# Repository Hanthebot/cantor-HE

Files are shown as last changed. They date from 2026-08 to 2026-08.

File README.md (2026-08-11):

# cantor-HE
42 key column staggered split, now with hall effect (WIP)

> Warning! The hardware should work fine, but firmware was not verified yet due to flashing issue.

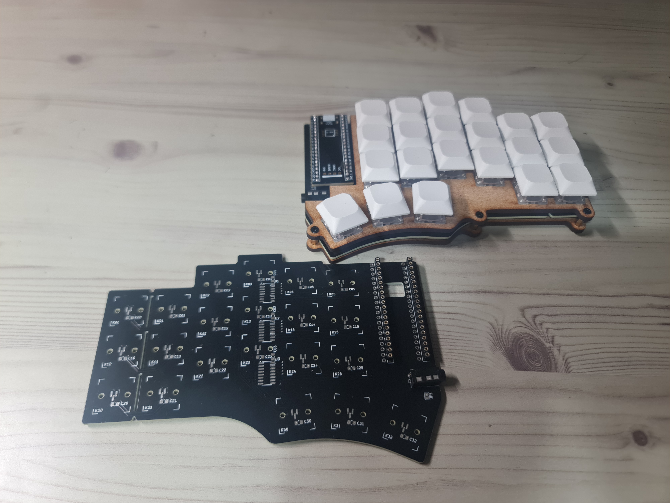
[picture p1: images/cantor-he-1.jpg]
cantor-he


Hall-effect variant of [Cantor](https://github.com/diepala/cantor), a 42-key split keyboard.

Wooting compatible, reversible, qmk/vial support, and sharing PCB dimension with official Cantor

Firmware / schematics based on [TrueStrike42](https://github.com/byungyoonc/TrueStrike42)

## Preparation

### Board
| Component | Qty |
| --- | --- |
| PCB | 2 |
| SOT-23 SS49E | 42  |
| SOIC-16 74HC4051(D)  | 6 |
| 0805 0.1uf capacitor | 48  |
| PJ320A TRRS socket | 2 |
| Blackpill MCU | 2 |
- For capacitor, 0.1~1uf should be fine
- And obviously, USB-C cable of your choice (with machine) and TRS/TRRS cable of your choice

### Case
- Option A: 3D printed case (I bet you can find one for Cantor)
- Option B: Cheap plate cut
  - requires heat insert and standoff
  - 3T mdf panel of A4 size can fit 2x top & bottom plate
      - and costs about $1
  - plate file provided in this repo
- I do not think original barebone design will work well, as switches are not soldered / mechanically connected.

| Component | Qty |
| --- | --- |
| M2 screw 6mm | 12  |
| M2 heat insert 3*3 | 12  |
| M2 standoff 7mm + 3mm head | 12  |
- Flathead screw was used
- Standoff can be shorter or longer - but I recommend 5mm at least

### Switches
| Component | Qty |
| --- | --- |
| Wooting compatible magnetic switch | 42  |
- While those without side pins should be fine, I'd use one with side pins so that they fix better
- Firmware fix may be required to use the opposite polarity

## [Build guide](GUIDE.md)
WIP. You may check images folder / [Boardloaf-HE's build guide](https://github.com/Hanthebot/Boardloaf-HE/blob/main/GUIDE.md). 

\+ jump back for side detection, firmware is shared between halves

Almost the only difference is that you can solder SOIC-16 multiplexor on either side, preferably at the back of the keyboard.

## Features
- Supports both APC and rapid trigger
- Cheap, simple, and working
- 3 multiplexor on each side, scanning 7 keys per mux

## Changes from Boardloaf-HE
- full duplex communication
- reversible SOIC-16 footprint
- except that, firmware remains largely identical.
- STM32F4x1 MCU, so key precision is expected to have been improved by ~= 10x

## Remarks
- Initial config recommendation: 30% / 20% / 20% / 10% / 10% / 20% (APC act / release; RT init dead / act offset / release offset / bottom dead)
- More documentation: to be done
- Case
  - if your case works for official Cantor, it must work for this
- Random
  - PCB schematics are almost directly from TrueStrike42

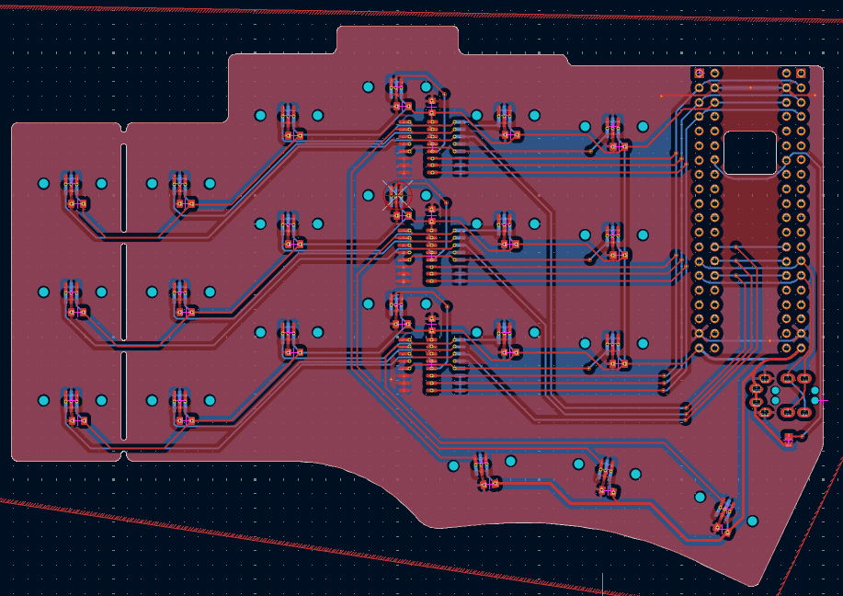
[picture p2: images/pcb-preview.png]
PCB


## Sponsorship
PCB was generously sponsored by [PCBWay](https://www.pcbway.com/)! Their PCB was indeed of high quality. I did not go with options like matte coating or ENIG, but the board was generally better.

Apart from their great quality, what I felt different was their customer service. There were real human involved in production / communication process and you could feel that they want to help you. In the world filled by chatbot / hallucination, such experience is very rare indeed.

If you are designing a PCB & want some human to check it beforehand, I think PCBWay is superb. They will save you trial and errors.

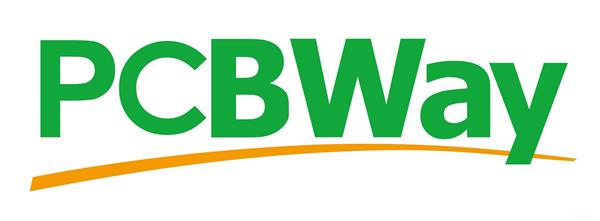
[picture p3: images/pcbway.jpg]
PCBWay


## Licenses
All code under firmware folder, along with HW, follows GPL v3.
- inherited from TrueStrike42 / Cantor respectively.
- reversible SOT23 / SOIC-16 footprint can be used with MIT.

Webapp follows MIT license.

## Disclaimer
Webapp and firmware (modification) were vibe coded.

Firmware needs future check.

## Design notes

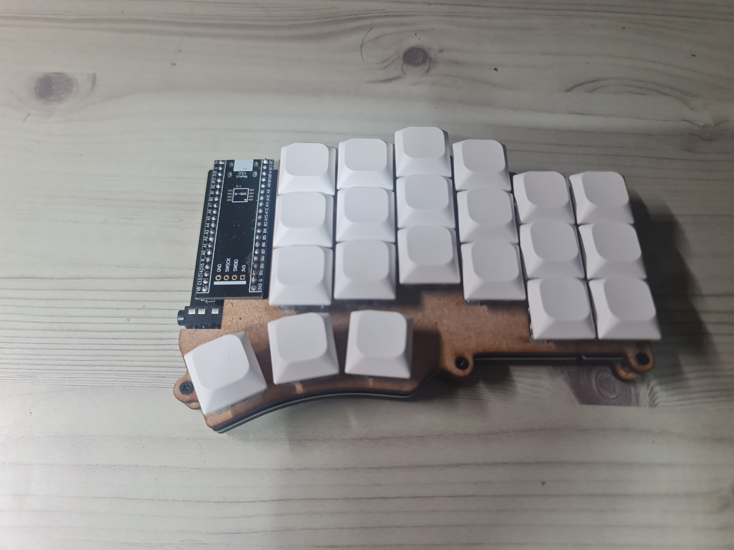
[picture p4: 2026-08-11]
images/cantor-he-2.jpg

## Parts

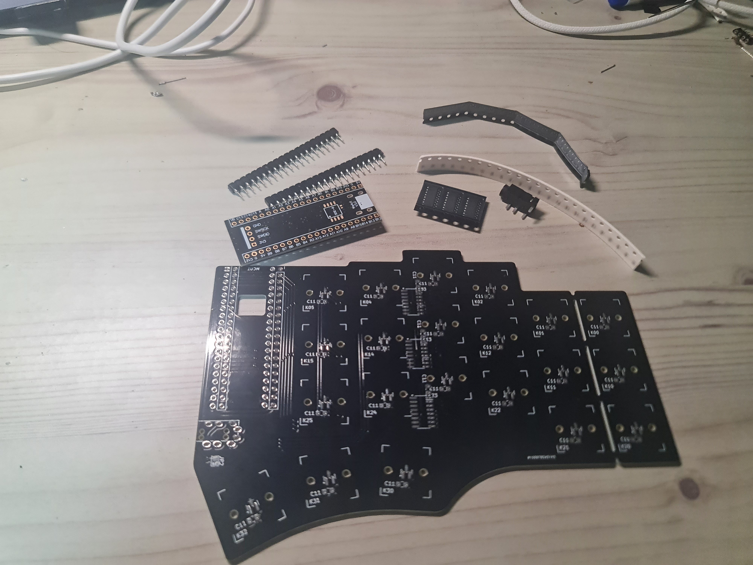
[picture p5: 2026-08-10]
images/components.jpg

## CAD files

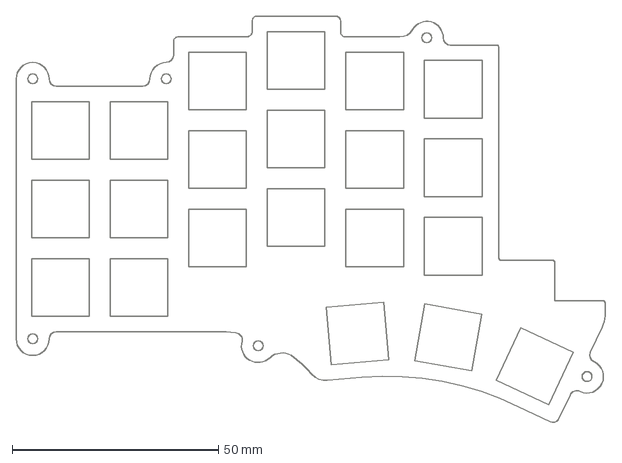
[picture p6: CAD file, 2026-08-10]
plate/Cantor_he_plate_top.dxf
143.0 x 98.7 mm

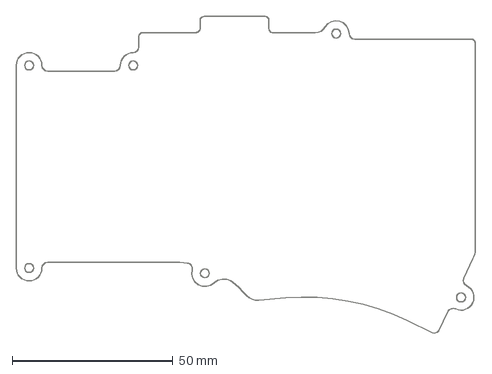
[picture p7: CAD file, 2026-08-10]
plate/Cantor_he_plate_bottom.dxf
143.0 x 98.7 mm

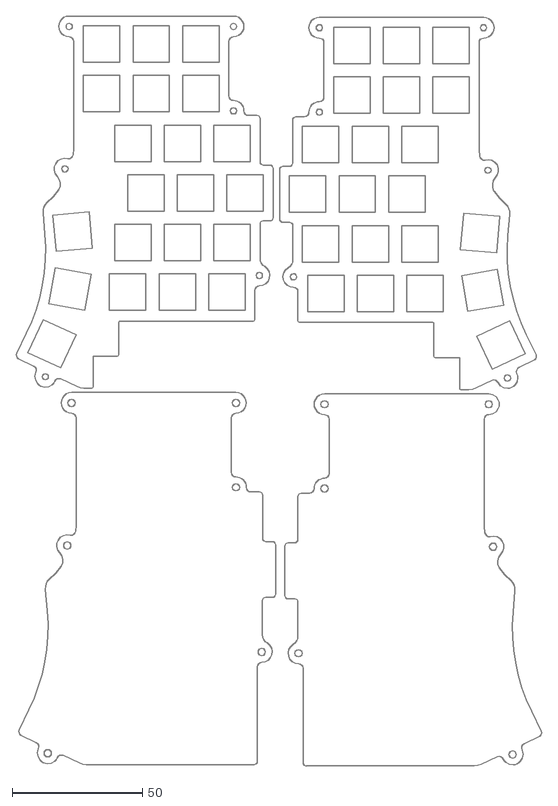
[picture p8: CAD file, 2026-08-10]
plate/plate_A4.dxf
201.6 x 287.9

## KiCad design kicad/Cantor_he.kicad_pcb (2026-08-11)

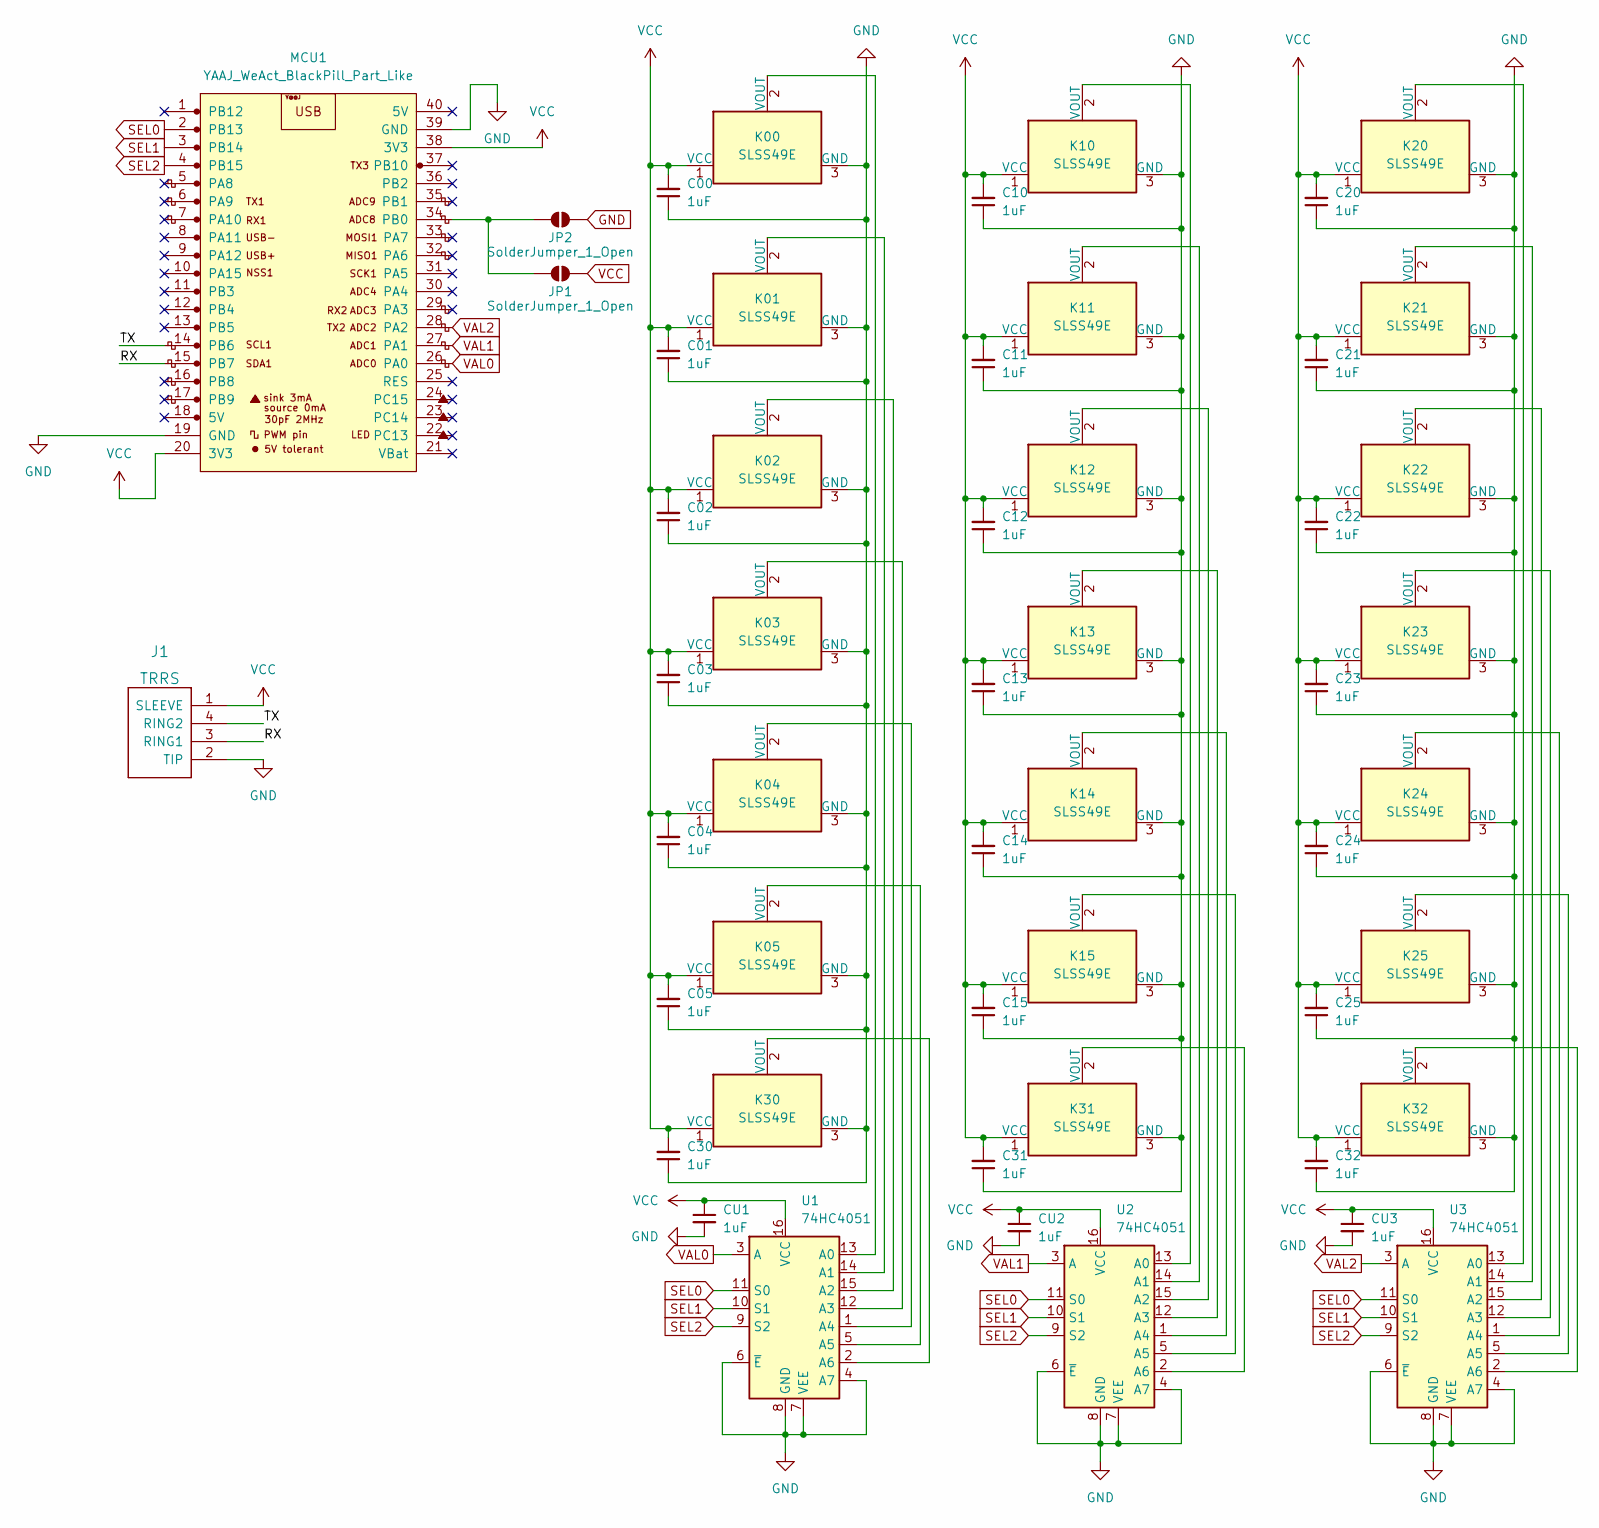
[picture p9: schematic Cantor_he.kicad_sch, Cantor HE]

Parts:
C00, C01, C02, C03, C04, C05, C10, C11, C12, C13, C14, C15, C20, C21, C22, C23, C24, C25, C30, C31, C32: 1uF; C_0805_2012Metric_Pad1.18x1.45mm_HandSolder
CU1, CU2, CU3: 1uF; C_0805_2012Metric_Pad1.18x1.45mm_HandSolder
J1: TRRS; MJ-4PP-9_Cantor_MX_TX-RX_Crossover
JP1, JP2: SolderJumper_1_Open; SolderJumper-2_P1.3mm_Open_TrianglePad1.0x1.5mm
K00, K01, K02, K03, K04, K05, K10, K11, K12, K13, K14, K15, K20, K21, K22, K23, K24, K25, K30, K31, K32: SLSS49E; HE-Switch-1U
MCU1: YAAJ_WeAct_BlackPill_Part_Like; Cantor_DS_YAAJ_WeAct_BlackPill_2
U1, U2, U3: 74HC4051; reversible-SOIC-16_3.9x9.9mm_P1.27mm

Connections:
/RX: J1.3 (RING1), MCU1.15 (PB7)
/TX: J1.4 (RING2), MCU1.14 (PB6)
GND: C00.1, C01.1, C02.1, C03.1, C04.1, C05.1, C10.1, C11.1, C12.1, C13.1, C14.1, C15.1, C20.1, C21.1, C22.1, C23.1, C24.1, C25.1, C30.1, C31.1, C32.1, CU1.2, CU2.2, CU3.2, J1.2 (TIP), JP2.2 (B), K00.3 (GND), K01.3 (GND), K02.3 (GND), K03.3 (GND), K04.3 (GND), K05.3 (GND), K10.3 (GND), K11.3 (GND), K12.3 (GND), K13.3 (GND), K14.3 (GND), K15.3 (GND), K20.3 (GND), K21.3 (GND), K22.3 (GND), K23.3 (GND), K24.3 (GND), K25.3 (GND), K30.3 (GND), K31.3 (GND), K32.3 (GND), MCU1.19 (GND), MCU1.39 (GND), U1.4 (A7), U1.6 (~E), U1.7 (VEE), U1.8 (GND), U2.4 (A7), U2.6 (~E), U2.7 (VEE), U2.8 (GND), U3.4 (A7), U3.6 (~E), U3.7 (VEE), U3.8 (GND)
unnamed: JP1.1 (A), JP2.1 (A), MCU1.34 (PB0)
unnamed: K00.2 (VOUT), U1.13 (A0)
unnamed: K01.2 (VOUT), U1.14 (A1)
unnamed: K02.2 (VOUT), U1.15 (A2)
unnamed: K03.2 (VOUT), U1.12 (A3)
unnamed: K04.2 (VOUT), U1.1 (A4)
unnamed: K05.2 (VOUT), U1.5 (A5)
unnamed: K10.2 (VOUT), U2.13 (A0)
unnamed: K11.2 (VOUT), U2.14 (A1)
unnamed: K12.2 (VOUT), U2.15 (A2)
unnamed: K13.2 (VOUT), U2.12 (A3)
unnamed: K14.2 (VOUT), U2.1 (A4)
unnamed: K15.2 (VOUT), U2.5 (A5)
unnamed: K20.2 (VOUT), U3.13 (A0)
unnamed: K21.2 (VOUT), U3.14 (A1)
unnamed: K22.2 (VOUT), U3.15 (A2)
unnamed: K23.2 (VOUT), U3.12 (A3)
unnamed: K24.2 (VOUT), U3.1 (A4)
unnamed: K25.2 (VOUT), U3.5 (A5)
unnamed: K30.2 (VOUT), U1.2 (A6)
unnamed: K31.2 (VOUT), U2.2 (A6)
unnamed: K32.2 (VOUT), U3.2 (A6)
SEL0: MCU1.2 (PB13), U1.11 (S0), U2.11 (S0), U3.11 (S0)
SEL1: MCU1.3 (PB14), U1.10 (S1), U2.10 (S1), U3.10 (S1)
SEL2: MCU1.4 (PB15), U1.9 (S2), U2.9 (S2), U3.9 (S2)
VAL0: MCU1.26 (PA0), U1.3 (A)
VAL1: MCU1.27 (PA1), U2.3 (A)
VAL2: MCU1.28 (PA2), U3.3 (A)
VCC: C00.2, C01.2, C02.2, C03.2, C04.2, C05.2, C10.2, C11.2, C12.2, C13.2, C14.2, C15.2, C20.2, C21.2, C22.2, C23.2, C24.2, C25.2, C30.2, C31.2, C32.2, CU1.1, CU2.1, CU3.1, J1.1 (SLEEVE), JP1.2 (B), K00.1 (VCC), K01.1 (VCC), K02.1 (VCC), K03.1 (VCC), K04.1 (VCC), K05.1 (VCC), K10.1 (VCC), K11.1 (VCC), K12.1 (VCC), K13.1 (VCC), K14.1 (VCC), K15.1 (VCC), K20.1 (VCC), K21.1 (VCC), K22.1 (VCC), K23.1 (VCC), K24.1 (VCC), K25.1 (VCC), K30.1 (VCC), K31.1 (VCC), K32.1 (VCC), MCU1.20 (3V3), MCU1.38 (3V3), U1.16 (VCC), U2.16 (VCC), U3.16 (VCC)

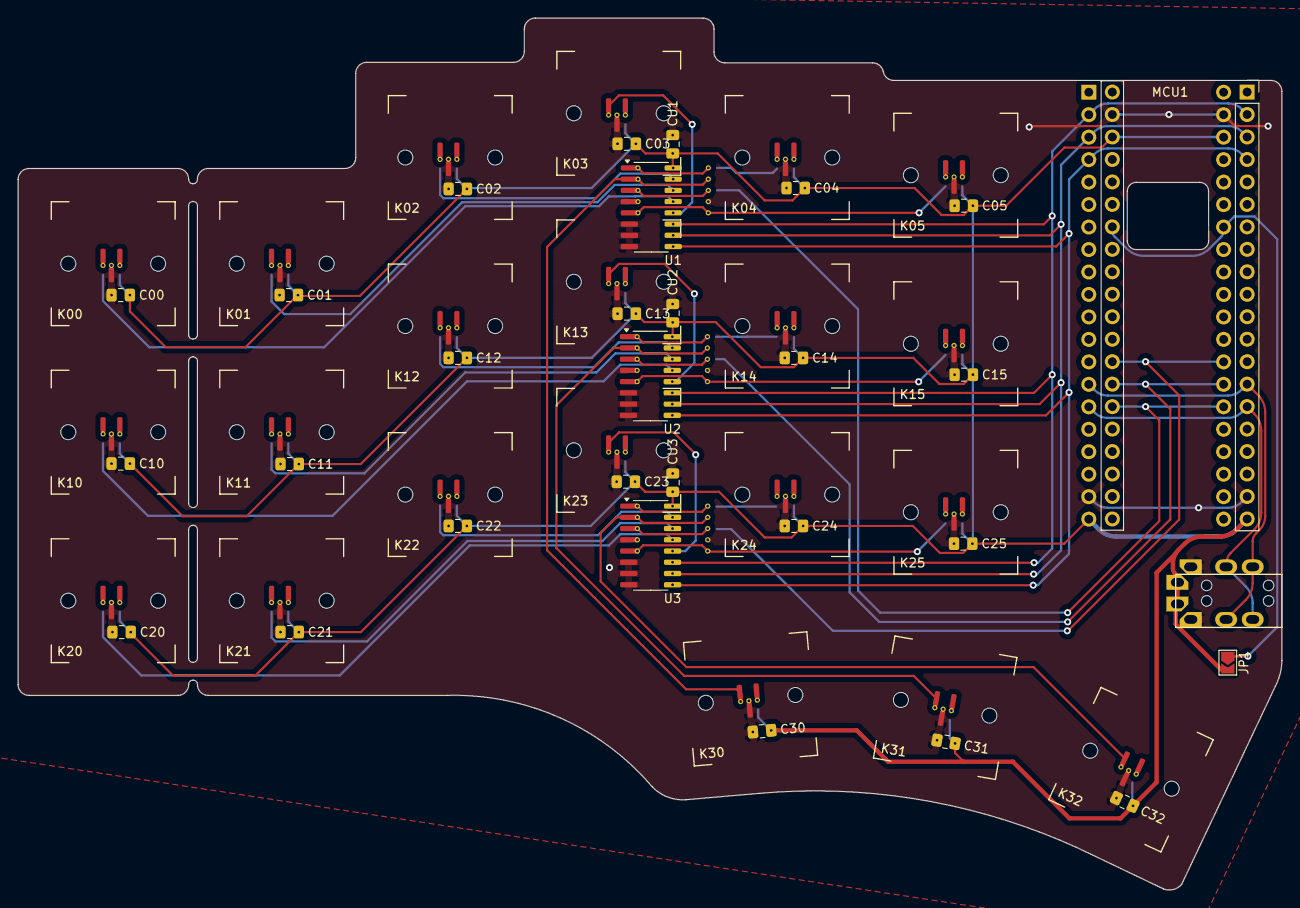
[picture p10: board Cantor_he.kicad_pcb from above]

Board: 2 copper layers, 142.9 x 98.6 mm, 52 parts (1 on the bottom side), 32 nets.

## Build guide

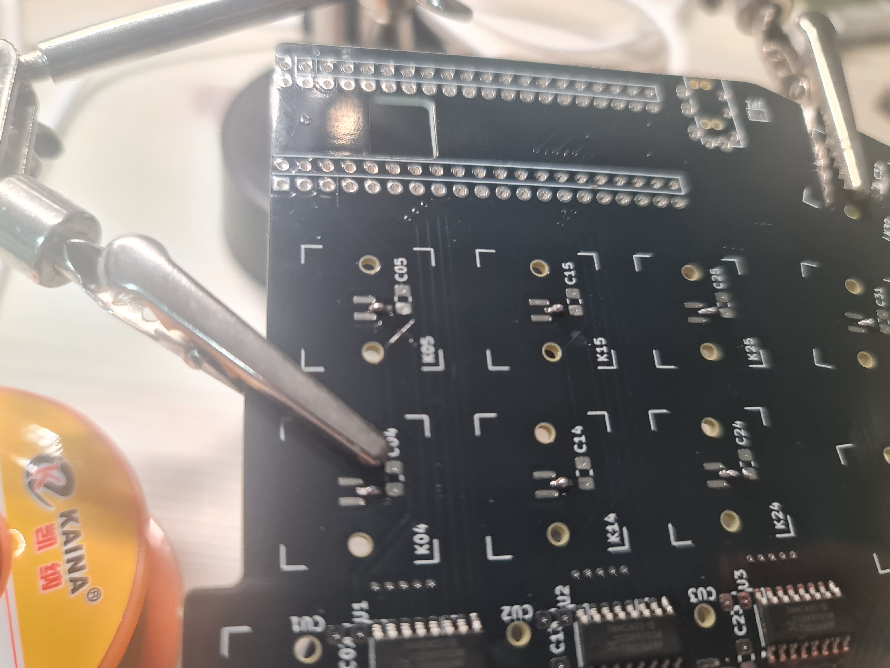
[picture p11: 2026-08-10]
images/solder-3-halleffect.jpg

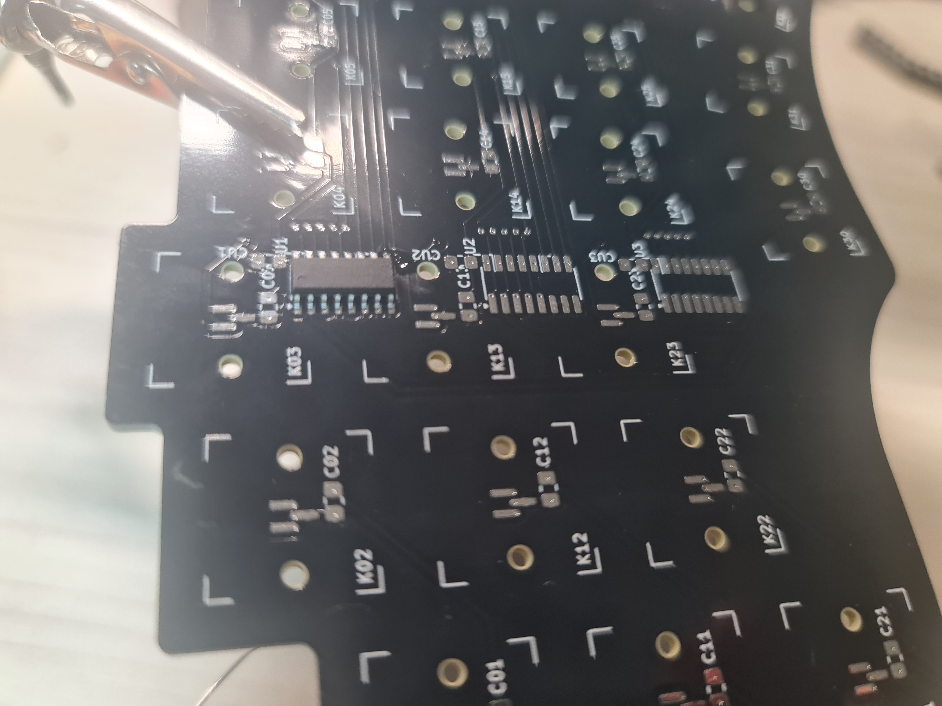
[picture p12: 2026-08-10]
images/solder-2-mux.jpg

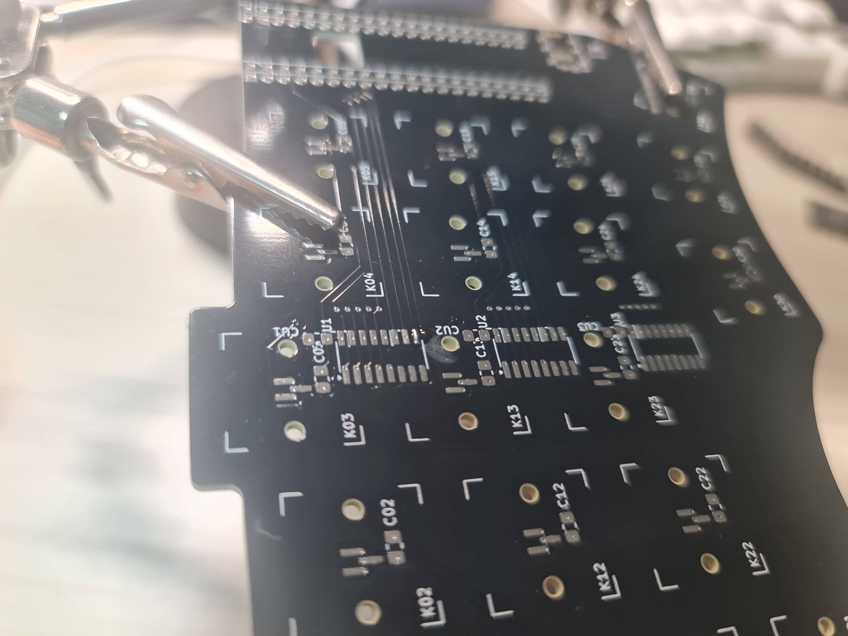
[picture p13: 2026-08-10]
images/solder-1-mux.jpg

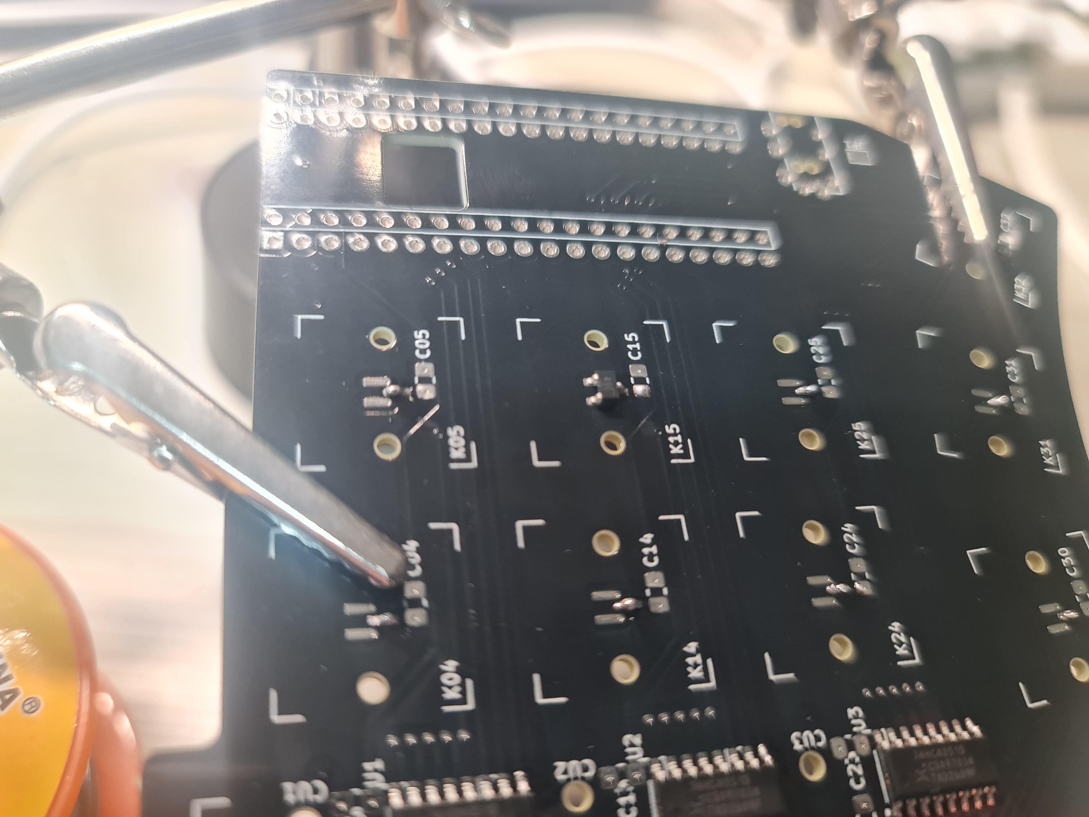
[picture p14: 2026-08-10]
images/solder-4-halleffect.jpg

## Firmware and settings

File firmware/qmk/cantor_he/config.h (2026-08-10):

#pragma once

#define HE_MATRIX_ROWS 3 // Rows per half
#define MATRIX_COLS 7 // Columns per half

#define MATRIX_ROW_PINS \
    { A0, A1, A2 }

#define ROWS_PER_COL \
    { 3, 3, 3, 3, 3, 3, 3 }

#define AMUX_MAX_COLS_COUNT 7

#define AMUX_SEL_PINS \
    { B13, B14, B15 }

#define AMUX_COL_CHANNELS \
    { 0, 1, 2, 3, 4, 5, 6 }

#define DEFAULT_ACTUATION_MODE 0
// "Light" preset based on 480-330 sensor range (~150 counts travel):
// APC actuation at 30% travel, release at 20% travel (10% hysteresis)
// RT deadzone at 30%, act offset ~10 counts (6.7% of travel), rel offset ~8 counts (5.3%)
#define DEFAULT_MODE_0_ACTUATION_LEVEL 300
#define DEFAULT_MODE_0_RELEASE_LEVEL 200
#define DEFAULT_MODE_1_INITIAL_DEADZONE_OFFSET 300
#define DEFAULT_MODE_1_ACTUATION_OFFSET 10
#define DEFAULT_MODE_1_RELEASE_OFFSET 8
#define DEFAULT_BOTTOM_DEADZONE 50
#define DEFAULT_EXTREMUM 1023
#define NOISE_CEILING_THRESHOLD 30
#define BOTTOMING_CALIBRATION_THRESHOLD 50
#define DEFAULT_NOISE_CEILING_SAMPLING_COUNT 30
#define DEFAULT_BOTTOMING_READING 0
#define DEFAULT_CALIBRATION_STARTER true

#define EECONFIG_KB_DATA_SIZE 253

#define VIA_CUSTOM_LIGHTING_ENABLE

// APP starts at 0x08004000 (WeAct HID bootloader in sector 0, custom linker script)
// STM32_BOOTLOADER_ADDRESS override is in rules.mk

// Split serial (STM32 USART1 full-duplex, PB6 TX / PB7 RX)
#define SERIAL_USART_FULL_DUPLEX
#define SERIAL_USART_TX_PIN B6
#define SERIAL_USART_RX_PIN B7
#define SERIAL_USART_DRIVER SD1

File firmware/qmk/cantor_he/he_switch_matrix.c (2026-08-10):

/* Copyright 2023 Cipulot, 2024 byungyoonc
 *
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
 * You should have received a copy of the GNU General Public License
 * along with this program.  If not, see <http://www.gnu.org/licenses/>.
 */

#include "he_switch_matrix.h"
#include "analog.h"
#include "print.h"
#include "wait.h"
#include "keyboard.h"

#if defined(__AVR__)
#    error "AVR platforms not supported due to a variety of reasons. Among them there are limited memory, limited number of pins and ADC not being able to give satisfactory results."
#endif

eeprom_he_config_t eeprom_he_config;
he_config_t        he_config;
bool he_live_stream_enabled = false;

const pin_t row_pins[]                               = MATRIX_ROW_PINS;
const pin_t amux_sel_pins[]                          = AMUX_SEL_PINS;
const pin_t amux_n_col_channels[AMUX_MAX_COLS_COUNT] = AMUX_COL_CHANNELS;
const uint8_t rows_per_col[]                         = ROWS_PER_COL;

#define AMUX_SEL_PINS_COUNT ARRAY_SIZE(amux_sel_pins)

static uint16_t sw_value[HE_MATRIX_ROWS][MATRIX_COLS];
static adc_mux adcMux[HE_MATRIX_ROWS];

void init_row(void) {
    for (uint8_t idx = 0; idx < HE_MATRIX_ROWS; ++idx) {
        palSetLineMode(row_pins[idx], PAL_MODE_INPUT_ANALOG);
        adcMux[idx] = pinToMux(row_pins[idx]);
    }
}

void init_amux(void) {
    for (uint8_t idx = 0; idx < AMUX_SEL_PINS_COUNT; ++idx) {
        gpio_set_pin_output(amux_sel_pins[idx]);
    }
}

void select_amux(uint8_t col) {
    uint8_t ch = amux_n_col_channels[col];
    for (uint8_t idx = 0; idx < AMUX_SEL_PINS_COUNT; ++idx) {
        gpio_write_pin(amux_sel_pins[idx], ch & (1 << idx));
    }
}

int he_init(void) {
    init_row();
    init_amux();
    return 0;
}

void he_noise_ceiling(void) {
    for (uint8_t row = 0; row < HE_MATRIX_ROWS; row++) {
        for (uint8_t col = 0; col < MATRIX_COLS; col++) {
            he_config.noise_ceiling[row][col] = 0;
        }
    }
    for (uint8_t i = 0; i < DEFAULT_NOISE_CEILING_SAMPLING_COUNT; i++) {
        for (uint8_t col = 0; col < MATRIX_COLS; col++) {
            select_amux(col);
            for (uint8_t row = 0; row < rows_per_col[col]; row++) {
                he_config.noise_ceiling[row][col] += he_readkey_raw(row);
            }
        }
        wait_ms(5);
    }
    for (uint8_t row = 0; row < HE_MATRIX_ROWS; row++) {
        for (uint8_t col = 0; col < MATRIX_COLS; col++) {
            he_config.noise_ceiling[row][col] /= DEFAULT_NOISE_CEILING_SAMPLING_COUNT;
        }
    }
}

bool he_matrix_scan(matrix_row_t current_matrix[]) {
    bool updated = false;

    for (uint8_t col = 0; col < MATRIX_COLS; col++) {
        select_amux(col);
        for (uint8_t row = 0; row < rows_per_col[col]; row++) {
            sw_value[row][col] = he_readkey_raw(row);
            if (he_config.bottoming_calibration) {
                if (he_config.bottoming_calibration_starter[row][col]) {
                    he_config.bottoming_reading[row][col] = sw_value[row][col];
                    he_config.bottoming_calibration_starter[row][col] = false;
                } else if (sw_value[row][col] < he_config.bottoming_reading[row][col]) {
                    he_config.bottoming_reading[row][col] = sw_value[row][col];
                }
            } else {
                updated |= he_update_key(&current_matrix[row], row, col, sw_value[row][col]);
            }
        }
    }

    return he_config.bottoming_calibration ? false : updated;
}

uint16_t he_readkey_raw(uint8_t row) {
    uint16_t sw_value = 0;
    sw_value = adc_read(adcMux[row]);
    return sw_value;
}

bool he_update_key(matrix_row_t* current_row, uint8_t row, uint8_t col, uint16_t sw_value) {
    bool current_state = (*current_row >> col) & 1;

    // Real Time Noise Floor Calibration
    if ((he_config.noise_ceiling[row][col] + NOISE_CEILING_THRESHOLD) < sw_value) {
        he_config.noise_ceiling[row][col]                           = sw_value;
        he_config.rescaled_mode_0_actuation_threshold[row][col]     = rescale(he_config.per_key_mode_0_actuation_threshold[row][col], 0, 1023, he_config.noise_ceiling[row][col], he_config.bottoming_reading[row][col]);
        he_config.rescaled_mode_0_release_threshold[row][col]       = rescale(he_config.per_key_mode_0_release_threshold[row][col], 0, 1023, he_config.noise_ceiling[row][col], he_config.bottoming_reading[row][col]);
        he_config.rescaled_mode_1_initial_deadzone_offset[row][col] = rescale(he_config.per_key_mode_1_initial_deadzone[row][col], 0, 1023, he_config.noise_ceiling[row][col], he_config.bottoming_reading[row][col]);
        he_config.rescaled_bottom_deadzone[row][col]                = rescale(he_config.per_key_bottom_deadzone[row][col], 0, 1023, he_config.noise_ceiling[row][col], he_config.bottoming_reading[row][col]);
    }

    // Bottom deadzone: if key is very close to bottoming, force pressed
    // regardless of mode. Prevents chatter when fully bottomed out.
    if (he_config.per_key_bottom_deadzone[row][col] > 0 && sw_value < he_config.rescaled_bottom_deadzone[row][col]) {
        if (sw_value < he_config.extremum[row][col]) {
            he_config.extremum[row][col] = sw_value;
        }
        if (!current_state) {
            *current_row |= (1 << col);
            return true;
        }
        return false;
    }
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

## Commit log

2026-08-10 FW / plate commit
    [Cantor_he_plate.kicad_pcb, Cantor_he_plate_bottom.dxf, Cantor_he_plate_bottom.kicad_pcb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]
2026-08-11 Updated PCB / gerber
    [Cantor_he-B_Cu.gbl, Cantor_he-B_Mask.gbs, Cantor_he-B_Paste.gbp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]

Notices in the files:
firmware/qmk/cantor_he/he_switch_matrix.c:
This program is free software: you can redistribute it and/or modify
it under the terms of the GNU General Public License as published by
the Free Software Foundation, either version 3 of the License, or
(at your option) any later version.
